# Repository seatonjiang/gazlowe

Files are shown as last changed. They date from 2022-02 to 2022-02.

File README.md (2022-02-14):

English | [简体中文](README.zh-CN.md)

<p align="center">
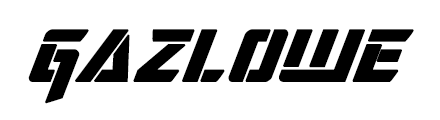
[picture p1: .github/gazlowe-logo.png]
    
</p>

<p align="center">
    <a href="https://github.com/seatonjiang/gazlowe/issues">
        
    </a>
    <a href="https://github.com/seatonjiang/gazlowe/pulls">
        
    </a>
    <a href="https://github.com/seatonjiang/gazlowe/blob/main/LICENSE">
        
    </a>
</p>

<p align="center">
    <a href="https://github.com/seatonjiang/gazlowe/issues">Report Bug</a>
    ·
    <a href="https://github.com/seatonjiang/gazlowe/issues">Request Feature</a>
</p>

<p align="center">64-key keyboard with customizable functions and key layouts</p>

## ✨ Keyboard Introduction

Gazlowe is a 64-key keyboard with new directional keys and two new custom keys around the directional keys compared to the common 60% keyboards. the ideal keyboard for R&D engineers!

## 📷 Keyboard Pictures

### Effect show

<p align="center">
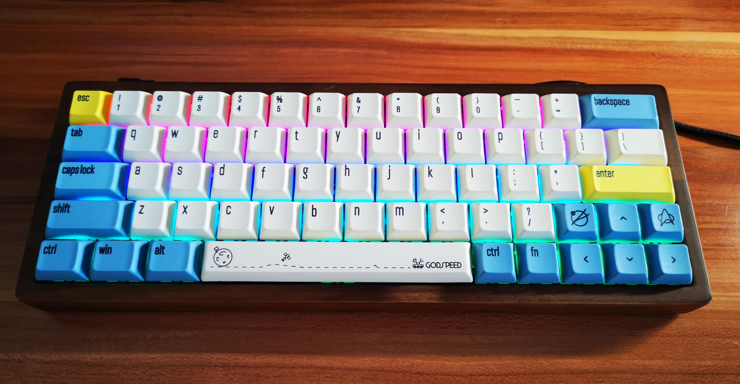
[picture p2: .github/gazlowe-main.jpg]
    
</p>

### PCB rendering

<p align="center">
    
</p>

### Gerber preview

<p align="center">
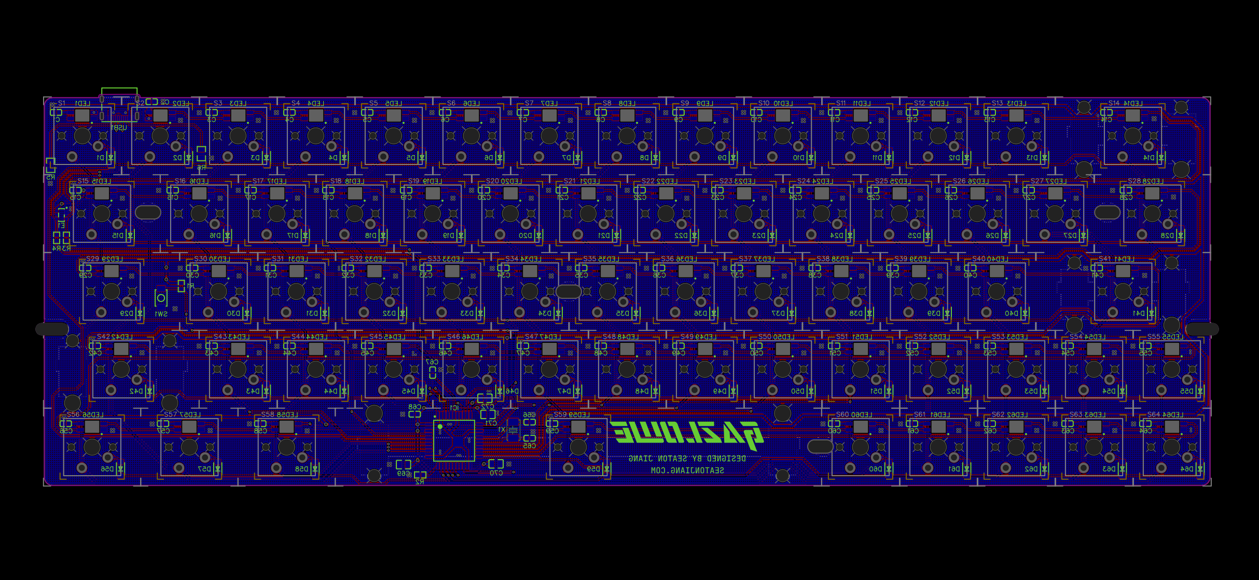
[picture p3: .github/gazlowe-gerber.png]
    
</p>

## 🛠️ Firmware Compilation

Gazlowe's firmware is built using QMK, to compile the firmware please refer to the [documentation](https://docs.qmk.fm/#/newbs_getting_started) for building a QMK development environment, QMK firmware can also be generated via the [ruiqimao/qmkbuilder](https:// github.com/ruiqimao/qmkbuilder) project, and the generated firmware can be converted to configuration files via the [noroadsleft/kbf_qmk_converter](https://github.com/noroadsleft/kbf_qmk_converter) project. to a configuration file. The default firmware for this project can be obtained from the [Releases](https://github.com/seatonjiang/gazlowe/releases) page.

### Step 1：Copy firmware directory

Copy the project `firmware/gazlowe` directory to the `qmk_firmware/keyboards/` directory.

### Step 2：Compiling firmware

Use the `qmk compile` command to compile the firmware, `default` refers to the keyboard layout.

```bash
qmk compile -kb gazlowe -km default
```

### Step 3：Flashing firmware

Connect the keyboard to the computer and put the keyboard into DFU (bootloader) mode by tapping the `RESET` button on the bottom of the motherboard, `Windows` or `macOS` platforms can be burned using [QMK Toolbox](https://github.com/qmk/qmk_toolbox/releases) Firmware, `Linux` platforms need to be burned using the following command.

```bash
qmk flash -kb gazlowe -km default
```

## ⚙️ PCB Proofing

The PCB design has been tested for full functionality and the `Gerber` file for the project can be obtained from the [Releases](https://github.com/seatonjiang/gazlowe/releases) page, which contains all the process layers.PCB prototype order board thickness select `1.6 mm`, outer copper thickness select `1 ounce`, pad plating recommended to select `sink gold` (can also choose `lead spray tin`), sink gold thickness select `1U`, the final order note `no half-hole process`.

## ⌨️ Specification Information

### Keyboard layout

The default firmware compiles a three-layer layout (the default layout is shown below). For a more detailed keyboard layout, please refer to the [instruction document](https://github.com/seatonjiang/gazlowe/blob/main/layout/README.md).

<p align="center">
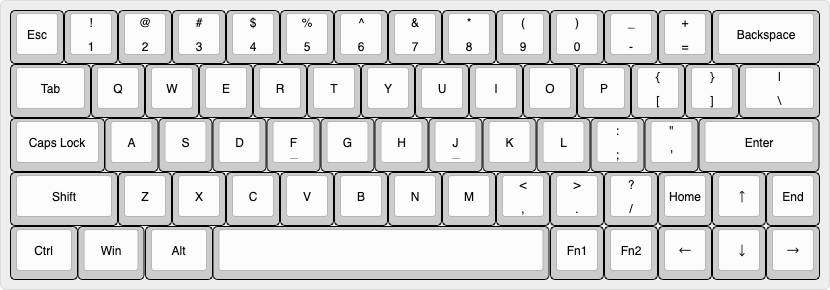
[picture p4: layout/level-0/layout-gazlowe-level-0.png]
    
</p>

### Keycap size

For details such as keycap size and corresponding quantity, please refer to the [instruction document](https://github.com/seatonjiang/gazlowe/blob/main/layout/keycap/README.md).

<p align="center">
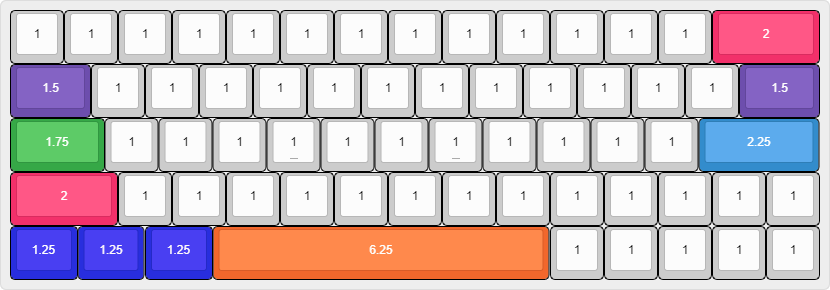
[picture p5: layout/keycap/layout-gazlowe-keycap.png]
    
</p>

### Positioning plate and satellite axis

For details such as satellite axis dimensions and corresponding quantities, please refer to the [instruction document](https://github.com/seatonjiang/gazlowe/blob/main/plate/README.md).

<p align="center">
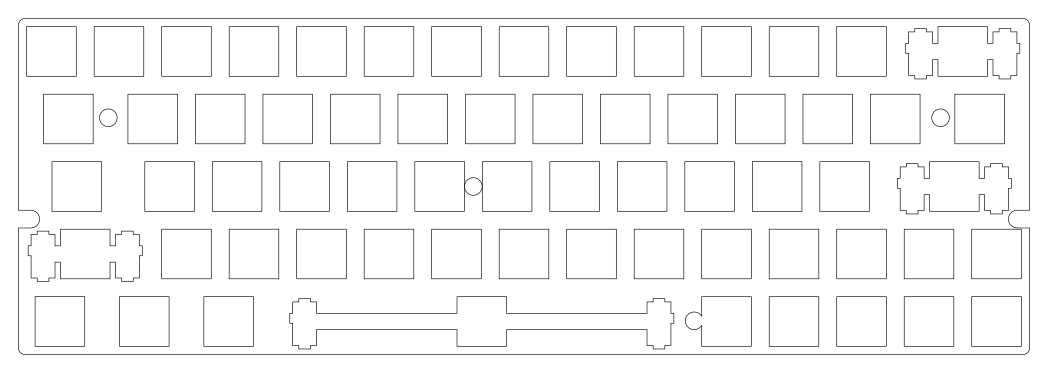
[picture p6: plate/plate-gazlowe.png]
    
</p>

## 📂 Structure

A quick look at the folder structure of this project.

```bash
gazlowe
├── bom
│   └── (some bom files)
├── firmware
│   └── (some firmware files)
├── graphics
│   └── (some graphics files)
├── layout
│   └── (some layout files)
├── pcb
│   └── (some pcb files)
├── plate
│   └── (some plate files)
└── schematic
    └── (some schematic files)
```

## 🤝 Contributing

We welcome all contributions. You can submit any ideas as pull requests or as issues, have a good time! :)

## 📃 License

The project is released under the GNU General Public License v3.0, see the [LICENCE](https://github.com/seatonjiang/gazlowe/blob/main/LICENSE) file for details.

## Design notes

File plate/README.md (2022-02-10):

## Satellite axis size

| Specification | Quantity |
| --- | --- |
| 6.25U | 1 |
| 2U | 3 |

## Plate size

Plate files and images can be generated online through the [Plate & Case Builder](http://builder.swillkb.com/) website.

plate

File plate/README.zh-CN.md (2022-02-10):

## 卫星轴尺寸

| 规格  | 数量 |
| ----- | ---- |
| 6.25U | 1 |
| 2U | 3 |

## 定位板尺寸

定位板文件和图片可以通过 [Plate & Case Builder](http://builder.swillkb.com/) 网站在线生成。

plate

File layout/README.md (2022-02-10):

## Keyboard layout

Keyboard layout files and images can be generated through the [ijprest/keyboard-layout-editor](https://github.com/ijprest/keyboard-layout-editor) project.

### First layer layout

layout-level-0

### Second layer layout

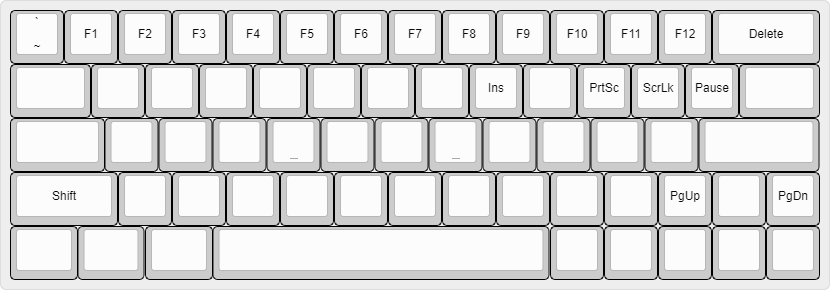
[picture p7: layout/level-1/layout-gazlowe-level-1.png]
layout-level-1


### Third layer layout

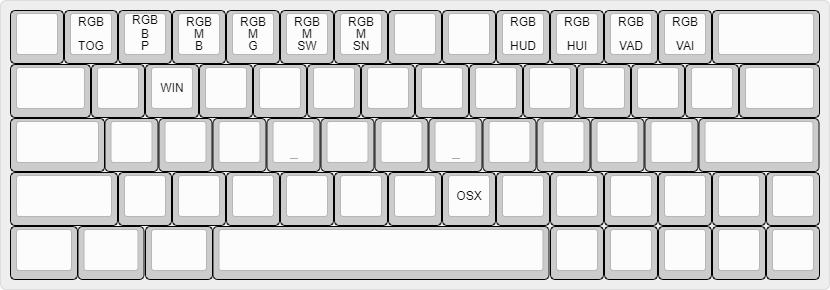
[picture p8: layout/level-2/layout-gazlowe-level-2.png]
layout-level-2


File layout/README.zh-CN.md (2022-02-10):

## 键盘布局

键盘布局文件和图片可以通过 [ijprest/keyboard-layout-editor](https://github.com/ijprest/keyboard-layout-editor) 项目生成。

### 第一层布局

layout-level-0

### 第二层布局

layout-level-1

### 第三层布局

layout-level-2

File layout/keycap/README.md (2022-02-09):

## Keycap size

| Specification | Quantity |
| --- | --- |
| 1U | 54 |
| 1.25U | 3 |
| 1.5U | 2 |
| 1.75U | 1 |
| 2U | 2 |
| 2.25U | 1 |
| 6.25U | 1 |

layout-keycap

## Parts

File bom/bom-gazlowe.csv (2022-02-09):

ID | Name | Designator | Footprint | Quantity | Manufacturer Part | Manufacturer | Supplier | Supplier Part
1 | 100nF | C69,C70,C71,C72 | C0805 | 4 | CC0805KRX7R9BB104 | YAGEO | LCSC | C49678
2 | 5.1KΩ | R5,R6 | R0805 | 2 | CR-05JL7---5K1 | Viking Tech | LCSC | C416158
3 | 10KΩ | R1,R2 | R0603 | 2 | 0603WAD1002T5E | Uniroyal Elec | LCSC | C167144
4 | 1N4148 | D1,D2,D3,D4,D5,D6,D7,D8,D9,D10,D11,D12,D13,D14,D15,D16,D17,D18,D19,D20,D21,D22,D23,D24,D25,D26,D27,D28,D29,D30,D31,D32,D33,D34,D35,D36,D37,D38,D39,D40,D41,D42,D43,D44,D45,D46,D47,D48,D49,D50,D51,D52,D53,D54,D55,D56,D57,D58,D59,D60,D61,D62,D63,D64 | SOD-123_L2.8-W1.8-LS3.7-RD | 64 | 1N4148W | Jingdao | LCSC | C115103
5 | 16MHz | X1 | OSC-SMD_2P-L5.0-W3.2 | 1 | XSHEELNANF-16MHZ | TAITIEN Elec | LCSC | C242221
6 | 22Ω | R3,R4 | R0603 | 2 | 0603WAF220JT5E | UniOhm | LCSC | C23345
7 | 100nF | C1,C2,C3,C4,C5,C6,C7,C8,C9,C10,C11,C12,C13,C14,C15,C16,C17,C18,C19,C20,C21,C22,C23,C24,C25,C26,C27,C28,C29,C30,C31,C32,C33,C34,C35,C36,C37,C38,C39,C40,C41,C42,C43,C44,C45,C46,C47,C48,C49,C50,C51,C52,C53,C54,C55,C56,C57,C58,C59,C60,C61,C62,C63,C64 | C0603 | 64 | CC0603KRX7R9BB104 | YAGEO | LCSC | C14663
8 | PRTR5V0U2X | E1 | SOT-143_L2.9-W1.3-P1.92-LS2.3-BL | 1 | PRTR5V0U2X | Yenji Elec | LCSC | C12333
9 | 22pF | C65,C66 | C0603 | 2 | CL10C220JB81PNC | SAMSUNG | LCSC | C170132
10 | TS-1088R-02026 | SW1 | SW-SMD_L3.9-W3.0-P4.45 | 1 | TS-1088R-02026 | XUNPU | LCSC | C455280
11 | 1uF | C67,C68 | C0603 | 2 | CL10A105KB8NNNC | SAMSUNG | LCSC | C15849
12 | ATMEGA32U4-AU | IC1 | QFP-44_L10.0-W10.0-P0.80-LS13.2-BL | 1 | ATMEGA32U4-AU | MICROCHIP | LCSC | C44854
13 | TYPE-C | USB1 | USB-C-SMD_TYPE-C16PIN | 1 | TYPE-C16PIN | SHOU HAN | LCSC | C393939
14 | WS2812B | LED1,LED2,LED3,LED4,LED5,LED6,LED7,LED8,LED9,LED10,LED11,LED12,LED13,LED14,LED15,LED16,LED17,LED18,LED19,LED20,LED21,LED22,LED23,LED24,LED25,LED26,LED27,LED28,LED29,LED30,LED31,LED32,LED33,LED34,LED35,LED36,LED37,LED38,LED39,LED40,LED41,LED42,LED43,LED44,LED45,LED46,LED47,LED48,LED49,LED50,LED51,LED52,LED53,LED54,LED55,LED56,LED57,LED58,LED59,LED60,LED61,LED62,LED63,LED64 | WS2812-3528 | 64
15 | Cherry MX | S1,S2,S3,S4,S5,S6,S7,S8,S9,S10,S11,S12,S13,S14,S15,S16,S17,S18,S19,S20,S21,S22,S23,S24,S25,S26,S27,S28,S29,S30,S31,S32,S33,S34,S35,S36,S37,S38,S39,S40,S41,S42,S43,S44,S45,S46,S47,S48,S49,S50,S51,S52,S53,S54,S55,S56,S57,S58,S59,S60,S61,S62,S63,S64 | CHERRY-MX-RGB | 64

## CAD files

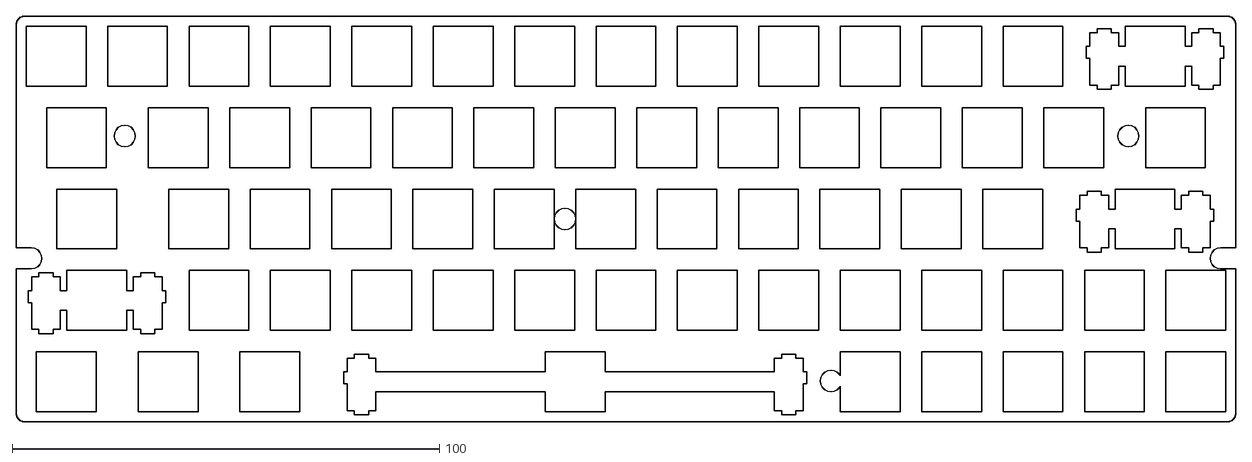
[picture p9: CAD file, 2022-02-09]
plate/plate-gazlowe.dxf
285.4 x 94.9

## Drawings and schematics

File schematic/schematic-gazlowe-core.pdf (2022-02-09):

R6 5.1K 66

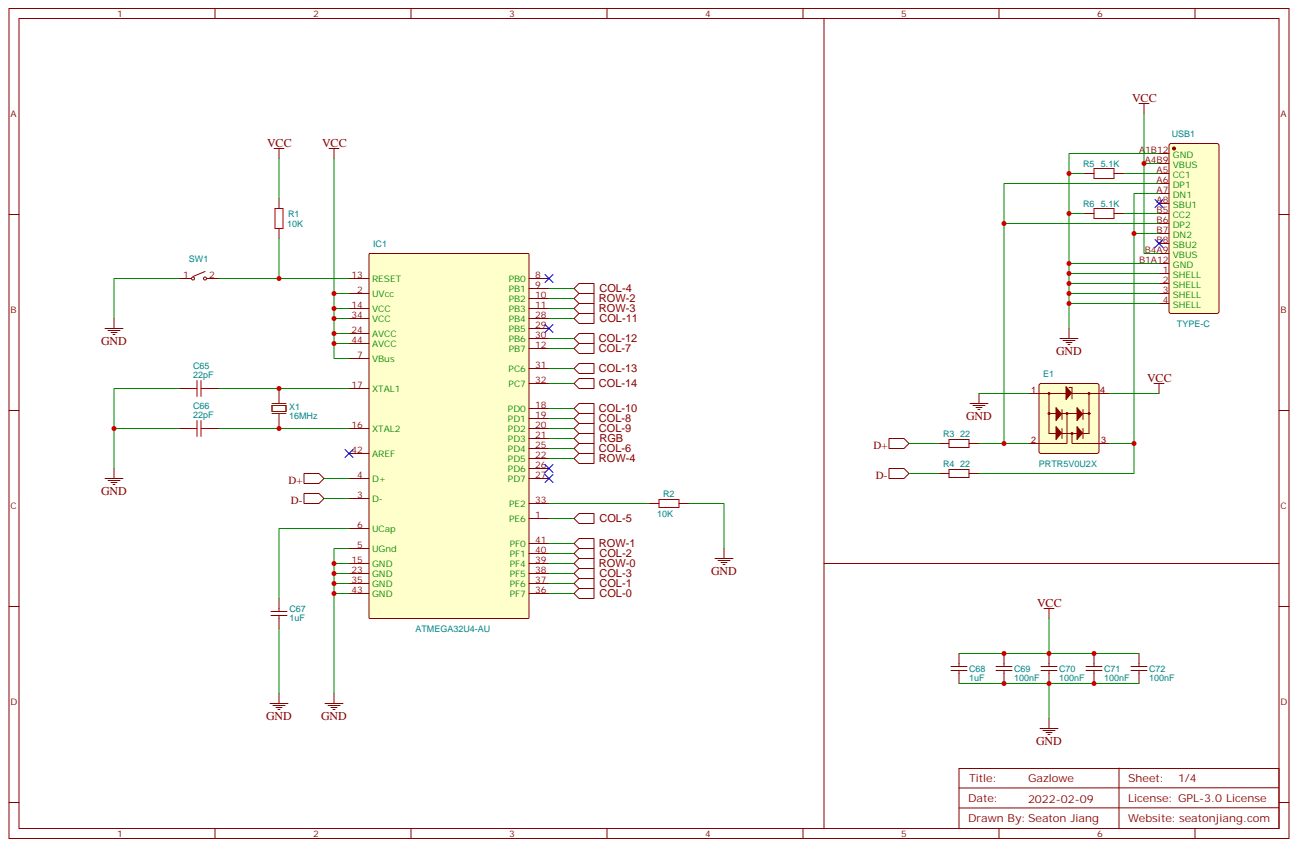
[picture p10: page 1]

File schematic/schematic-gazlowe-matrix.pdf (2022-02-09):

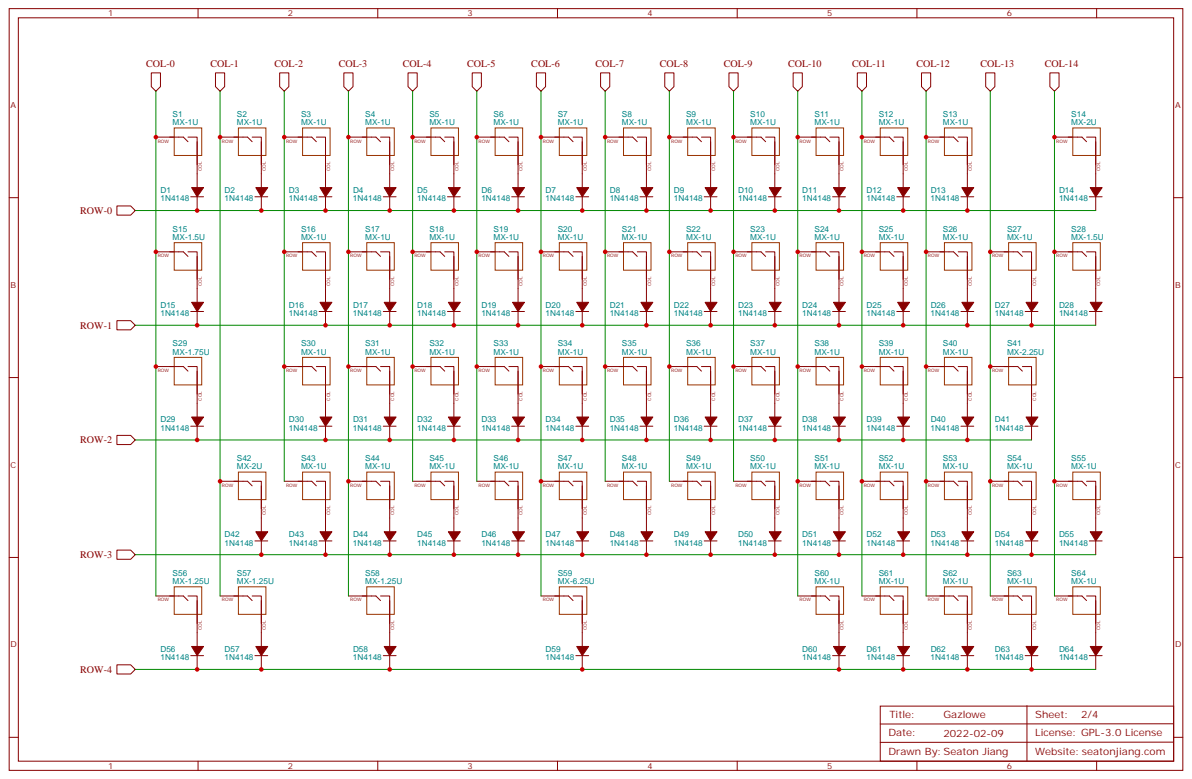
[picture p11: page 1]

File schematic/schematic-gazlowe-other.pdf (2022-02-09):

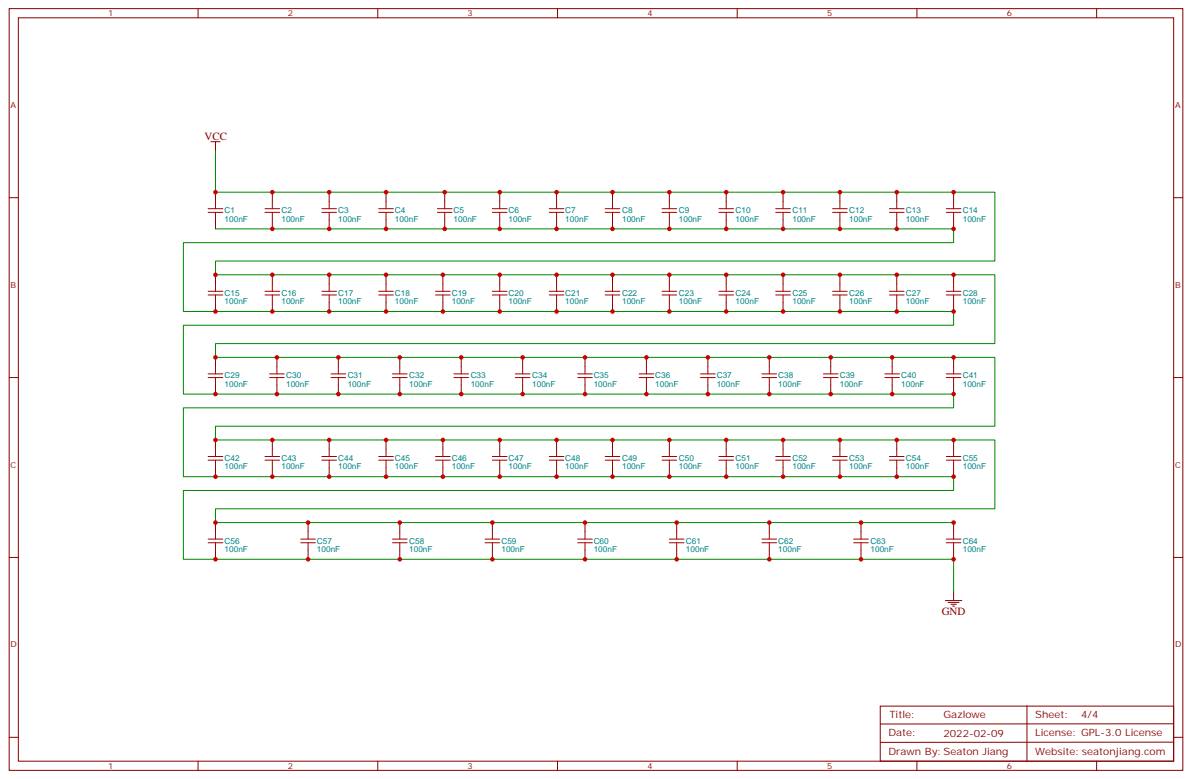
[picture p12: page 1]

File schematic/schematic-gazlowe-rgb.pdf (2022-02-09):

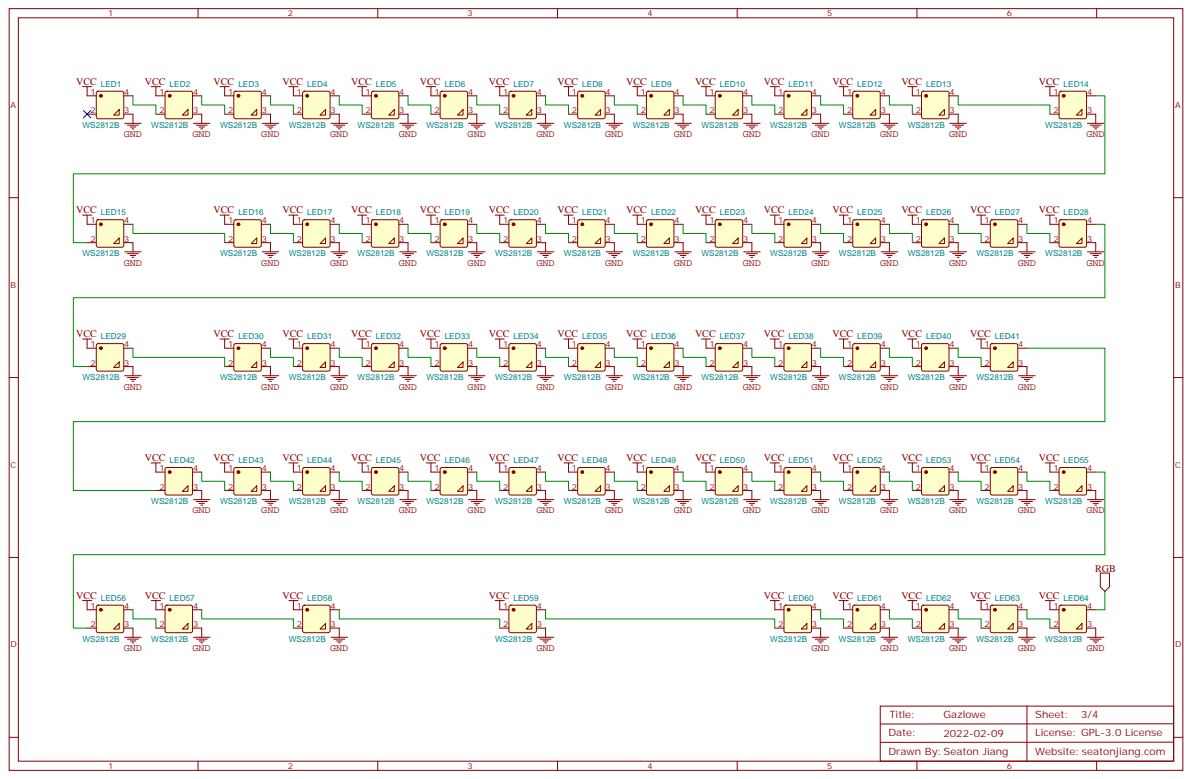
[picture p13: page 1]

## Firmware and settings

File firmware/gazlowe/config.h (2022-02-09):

/*
 * Copyright (C) 2022 Seaton Jiang <hi@seatonjiang.com>
 *
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
 * You should have received a copy of the GNU General Public License
 * along with this program.  If not, see <https://www.gnu.org/licenses/>.
 */

#pragma once

#include "config_common.h"

/* USB Device descriptor parameter */
#define VENDOR_ID       0x5633
#define PRODUCT_ID      0x1024
#define DEVICE_VER      0x0001
#define MANUFACTURER    Seaton Jiang
#define PRODUCT         Gazlowe

/* key matrix size */
#define MATRIX_ROWS 5
#define MATRIX_COLS 15

/* Keyboard Matrix Assignments */
#define MATRIX_ROW_PINS { F4, F0, B2, B3, D5 }
#define MATRIX_COL_PINS { F7, F6, F1, F5, B1, E6, D4, B7, D1, D2, D0, B4, B6, C6, C7 }

#define DIODE_DIRECTION COL2ROW

#define RGB_DI_PIN D3
#ifdef RGB_DI_PIN
#    define RGBLED_NUM 64
#    define RGBLIGHT_HUE_STEP 20
#    define RGBLIGHT_SAT_STEP 20
#    define RGBLIGHT_VAL_STEP 40
#    define RGBLIGHT_LIMIT_VAL 200
#    define RGBLIGHT_SLEEP
#    define RGBLIGHT_EFFECT_BREATHING
#    define RGBLIGHT_EFFECT_RAINBOW_SWIRL
#    define RGBLIGHT_EFFECT_SNAKE
#    define RGBLIGHT_EFFECT_STATIC_GRADIENT
#endif

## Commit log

2022-02-09 feat: add keyboard schematic
2022-02-09 feat: add keyboard bom
    [bom-gazlowe.csv]
2022-02-09 feat: add keyboard plate
    [plate-gazlowe.dxf]
2022-02-09 feat: add keyboard pcb
    [pcb-gazlowe.pcbdoc]
2022-02-09 fix: csv file format
    [bom-gazlowe.csv]
2022-02-09 docs: add gerber preview

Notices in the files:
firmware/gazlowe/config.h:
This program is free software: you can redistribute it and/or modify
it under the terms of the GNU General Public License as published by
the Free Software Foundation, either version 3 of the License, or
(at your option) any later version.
